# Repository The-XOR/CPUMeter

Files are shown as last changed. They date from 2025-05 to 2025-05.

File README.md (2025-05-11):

# CPUMeter
Una pazzia computer-motoristica 

Preliminari (sempre importanti):
- aprire il gauge, scollegare lo strumento a lancetta dal circuito elettronico interno e portare i fili fuori: verra' comandato direttamente dal circuito esterno.

- Lista della spesa:
  - n. 1 contagiri (senza, l'intero progetto perde un po' di senso). Quello utilizzato e' questo qui: https://it.aliexpress.com/item/1005007490570643.html
  - n. 1 DC/DC booster. Il gauge e' alimentato a 12 voltaggi, quindi serve un po' di sprint. Quello che ho utilizzato e' questo qui: https://it.aliexpress.com/item/1005006031037900.html
  - n. 1 RP2040-Zero (https://it.aliexpress.com/item/1005006865919374.html)
  - n. 1 resistenza 820ohm
  - tutti i componenti presenti nello schema
  
- Taratura DC/DC booster:
  collegare il DCDCB ai pin 1 et 2 del RP2040 (rispettivamente +5V e GND). Con un tester, regolare la tensione
  di uscita a 11.2V

- Software:
  Caricare il micropitone.uf2 sull'RP2040 
  Se non gia' installato, installare l'utility rshell con:
  python3 -m pip install rshell
  
  Copiare il file main.py sul rp2040:
  rshell -p /dev/ttyACM0 --buffer-size 512 cp main.py /pyboard/main.py

- Uso:
  Una volta avviato il software del microcontrollore, questo aspetta un byte (valori da 0 a 100) corrispondente
  al valore del carico attuale della CPU. Se il byte viene ricevuto correttamente, si accende la retroilluminazione del gauge e la lancetta viene portata sul valore corrispondente

Questa repository contiene una sorta di scheletro in linguaggio autohotkey per mandare periodicamente (ogni secondo) il valore di carico della CPU sulla porta seriale

## Test:
stty -F /dev/ttyACM0 raw -echo
echo -n -e '\xN' > /dev/ttyACM0
dove N (esadecimale) va da 0 a 64

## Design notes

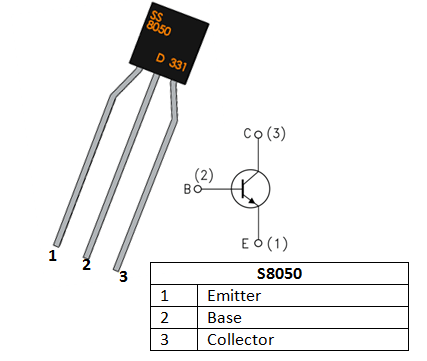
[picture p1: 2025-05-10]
S8050 pinout.png

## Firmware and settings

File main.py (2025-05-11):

from machine import Pin, PWM
import sys
import uselect
import time
import micropython

# Breve spiegazione der Duty cycle:
# On RP2040 with MicroPython, duty is a 16-bit value: 0–65535
# 0 = 0% on-time, 65535 = 100% on-time
# Esempio:50% duty = pwm.duty_u16(32768)

# Inizializzazione oggetti vari
micropython.kbd_intr(-1) # Senza di cus, il byte 0x03 viene interpretato come 'break' e il programma crescia 
pwm_pin = Pin(15) # PIN PWM: 15
pwm = PWM(pwm_pin)
retro = Pin(8, Pin.OUT)
poller = uselect.poll()
poller.register(sys.stdin, uselect.POLLIN)
pwm.freq(150000) # 150 kilocicli, mica na pezza a fiori!
# i valori trovati con "Taratura"
min_pwm=20500
max_pwm = 59500
last_received = time.time() # timeout comunicazione

def set_pwm(duty):
    retro.value(0 if duty < min_pwm else 1)
    if duty < min_pwm:
        duty = min_pwm
    print("duty",duty)
    print("rtr", retro.value())
    pwm.duty_u16(duty)

def getvalue():
    global last_received
    buf = bytearray(1)
    if poller.poll(50):          
        if sys.stdin.readinto(buf):
            last_received = time.time()
            if 0 <= buf[0] <= 100:
                return buf[0]     # 0–255 integer
    return None

# <<<<<<<<<<<<<<<<<<<<<<<< LUP >>>>>>>>>>>>>>>>>>>>>>>>>>
set_pwm(0)
print("Start!")
try:
    while True:
        cpu_load = getvalue()
        if cpu_load != None:
            print("Carico CPU =", cpu_load)            
            cpu_load = int(cpu_load * (max_pwm-min_pwm) / 100) + min_pwm            
            set_pwm(cpu_load)

        if time.time() - last_received > 10: # almeno 1 dato ogni 10 secondi, altrimenti spegni (doll combing)
            set_pwm(0)
        time.sleep(0.05)

except Exception as e:
    print("*** L'eccezione: ", e.value)
    set_pwm(0)
    
finally:
    set_pwm(0)
    pwm.deinit()    
    print("Qui abbiamo finito.")

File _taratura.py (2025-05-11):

from machine import Pin, PWM
import sys
import uselect
import time
import micropython

# Inizializzazione oggetti vari
pwm_pin = Pin(15) # PIN PWM: 15
pwm = PWM(pwm_pin)

# **** COLLEGARE UN PULSANTONE TRA PIN 8 E MASSA: AD OGNI PRESSIONE VIENE INCREMENTATO IL VALORE DI PIVUEMME ****
cambio = Pin(8, Pin.IN, Pin.PULL_UP)
poller = uselect.poll()
poller.register(sys.stdin, uselect.POLLIN)
pwm.freq(150000) # 150 kilocicli, mica na pezza a fiori!

# Breve spiegazione der Duty cycle:
# On RP2040 with MicroPython, duty is a 16-bit value: 0–65535
# 0 = 0% on-time, 65535 = 100% on-time
# Esempio:50% duty = pwm.duty_u16(32768)

min_pwm=20500
max_pwm = 59500

cur_pwm=min_pwm
step_pwm=1000
pwm.duty_u16(min_pwm)

try:
    while True:
        if cambio.value() == 0:
            cur_pwm=cur_pwm+step_pwm
            if cur_pwm > max_pwm:
                cur_pwm=min_pwm
            print("Current: ",cur_pwm)
            pwm.duty_u16(cur_pwm)
            while cambio.value() == 0:
                pass
        else:
            time.sleep(0.1)
        
        
except Exception as e:
    print("L'eccezione: ", e.value)
    
    
finally:
    pwm.deinit()    
    print("Fine.")
